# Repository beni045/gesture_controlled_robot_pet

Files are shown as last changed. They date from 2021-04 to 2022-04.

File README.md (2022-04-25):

# Gesture Controlled Robot Pet

Consider having a pet that is smart, responds to your commands without training, and even takes pictures for you! You don’t even have to pick up after or buy kibble for this pet! This is a dream come true for those craving an animal companion but cannot afford the time, money, or maintenance required for real animals. Robot pets are one example of how technology can assist in scenarios where companionship and fun are needed, but the handling and upkeep of real pets isn’t possible; especially in healthcare or senior homes.

Apart from doing normal pet things such as moving around and performing a few tricks, it can also perform robot tasks, like capturing photos with the camera in its nose. It can also remember you and follow you around for as long as you like. You can also deactivate this pet for some privacy and activate it back again when you feel like you need its company.

Through its camera “eyes”, this robot pet uses a combination of machine learning and computer vision techniques to see and respond to commands given through its owner’s body gestures. The robot pet can track, recognize, and perform a task such as following the user. The user is thus able to control the pet from a distance, enabling full autonomy.

<p align="center">
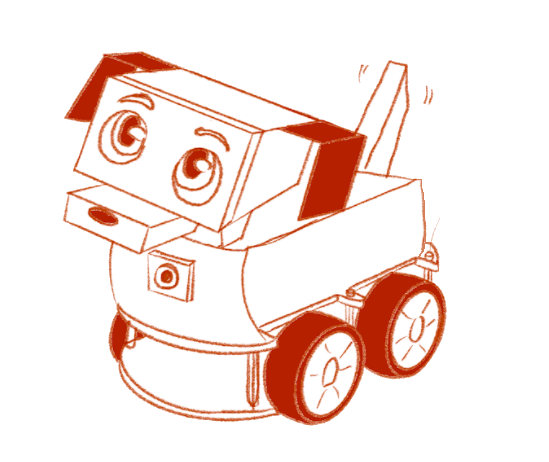
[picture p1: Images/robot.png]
  
</p>

# Repo
<p align="center">
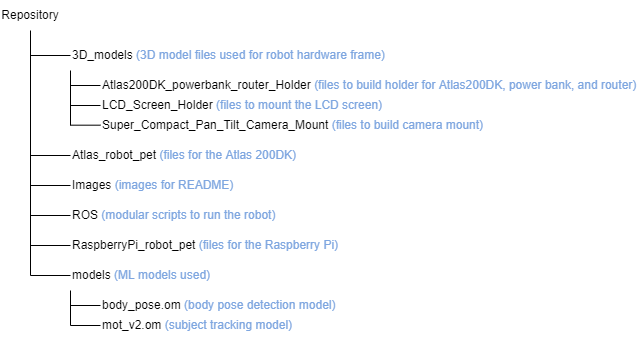
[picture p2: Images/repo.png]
  
</p>

# Gestures
Below are the gestures included in the repository.

Command | Gesture | Description | Output
------- | ------- | ----------- | ------
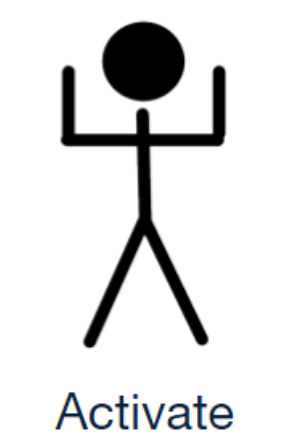
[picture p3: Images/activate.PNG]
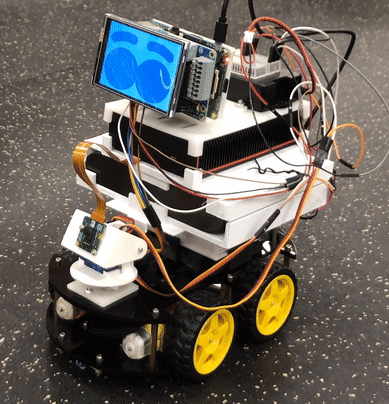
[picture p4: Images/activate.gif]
`Activate` |  | Robot starts functioning and responding to commands | 
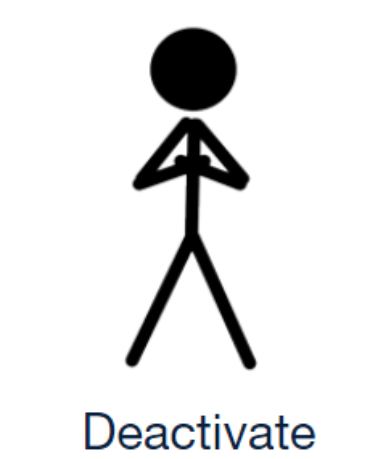
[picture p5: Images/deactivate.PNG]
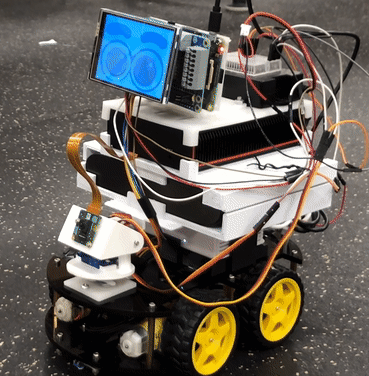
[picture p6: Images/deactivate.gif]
`Deactivate` |  | Robot goes to “sleep” state and can only be woken up by giving it activate command | 
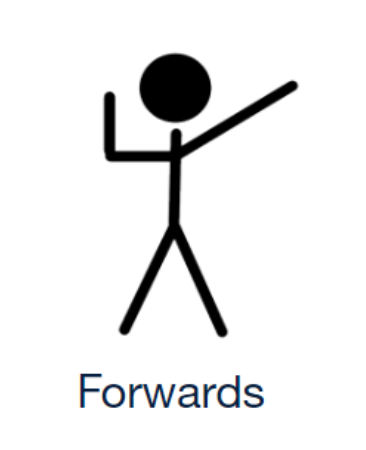
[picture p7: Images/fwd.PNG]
`Move Forwards` |  | Moves the robot forwards | 
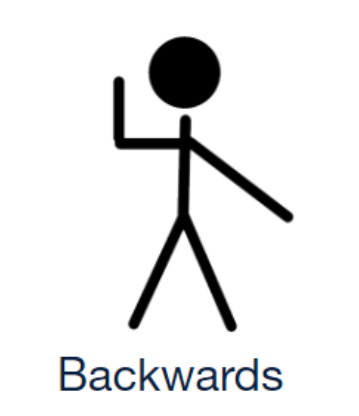
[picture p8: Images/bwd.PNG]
`Move Backwards` |  | Moves the robot backwards | 
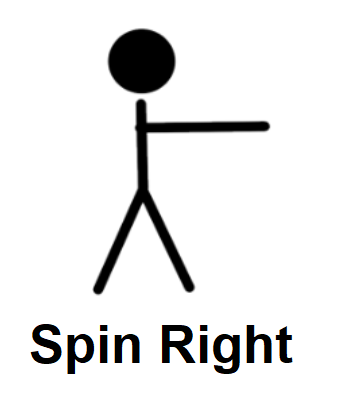
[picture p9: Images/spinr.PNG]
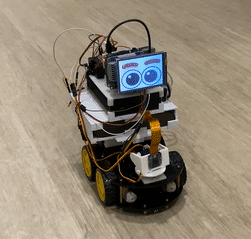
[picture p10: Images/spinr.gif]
`Spin Right` |  | Spins the robot right | 
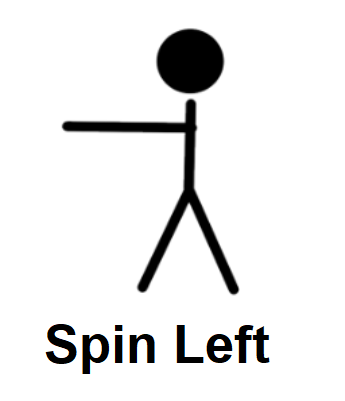
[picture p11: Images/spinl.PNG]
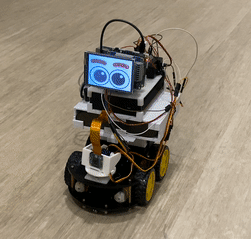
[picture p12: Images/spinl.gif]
`Spin Left` |  | Spins the robot left | 
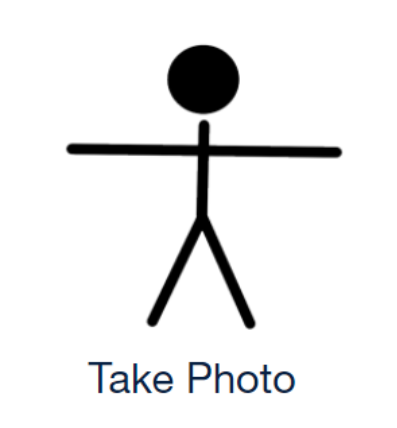
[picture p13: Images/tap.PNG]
`Take a Picture` |  | Initiates the routine to take a photo | 
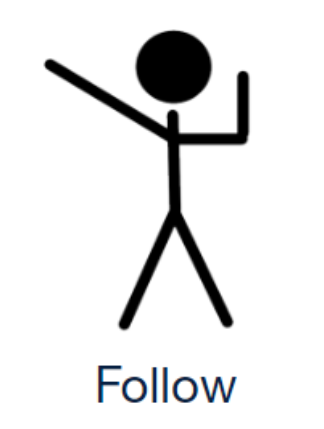
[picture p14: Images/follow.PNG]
`Follow` |  | Initiates the routine to follow the person who gave the follow gesture | 
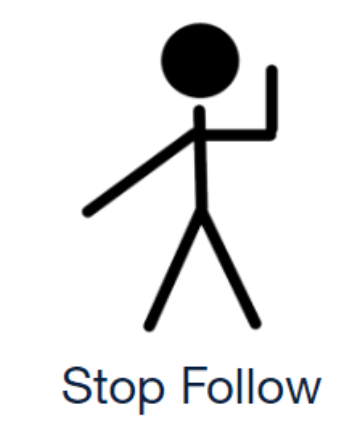
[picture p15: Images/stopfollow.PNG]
`Stop Follow` |  | Stops the follow routine if the robot is in follow mode | 

# Hardware
* [Huawei's Atlas 200DK](https://e.huawei.com/en/products/cloud-computing-dc/atlas/atlas-200)
* [Raspberry Pi (3+)](https://www.raspberrypi.org/products/raspberry-pi-4-model-b/)
* [Raspberry Pi Camera (Camera V2)](https://www.raspberrypi.org/products/camera-module-v2/)
* [Raspberry Pi LCD Screen (Kuman 3.5" Inch TFT LCD Display 480x320 RGB Pixels)](https://www.amazon.ca/Kuman-Display-480x320-Raspberry-Interface/dp/B01CQIPEO0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)
* [ELEGOO UNO Robot Car Base](https://www.amazon.ca/ELEGOO-Ultrasonic-Bluetooth-Intelligent-Educational/dp/B07485YQP8)
* [2 Servo Motors (SG90)](https://www.amazon.ca/gp/product/B07Z16DWGW/ref=ppx_yo_dt_b_asin_title_o05_s00?ie=UTF8&psc=1)
* [Krisdonia Power Bank](https://www.amazon.ca/Krisdonia-25000mAh-Portable-External-Macbooks/dp/B076GYGR6M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)
* [GL.iNet Router](https://www.gl-inet.com/products/gl-ar750/)

* Miscellaneous:
  * 3D printer
  * [Raspberry Pi Camera Ribbon Cable](https://www.amazon.ca/Raspberry-Camera-Ribbon-Cable-Module/dp/B0981DPWD9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)
  * 2 Ethernet Cables
  * Breadboard Jumper Cables
  * Screws

<p align="center">
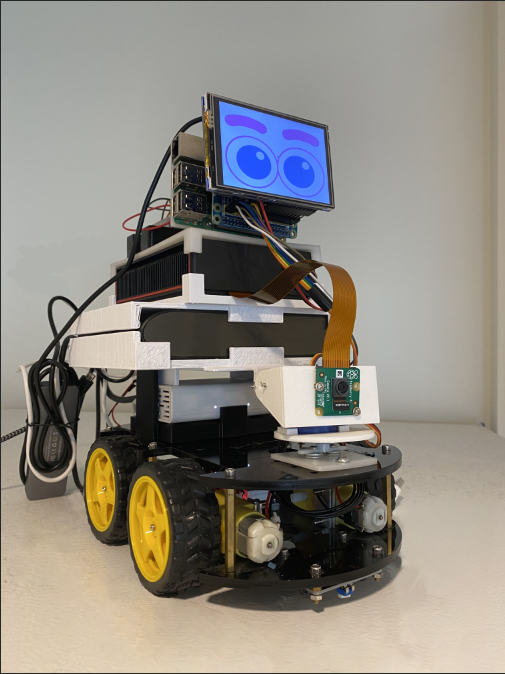
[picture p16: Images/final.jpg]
  
</p>

### Setup and Connection Notes
* Build robot base without using the Arduino or the ultrasonic sensors, you can find the instructions [here](https://drive.google.com/file/d/1nSlkYJ7oCfMkG1p-KDfVHdLQt3B4Nmo5/view)
* Connect robot base parts to Raspberry Pi (see pinout in RaspberryPi_robot_pet/server_v9.py)
* Connect Raspberry Pi Camera to CAMERA1 on the Atlas 200 DK, you can follow this [guide](https://support.huaweicloud.com/intl/en-us/qs-atlas200dkappc32/atlased_04_0006.html)
* Set the output voltage of the power bank to 12 V. (Hold the power button and then double click a few times.)
  * The Atlas Board can be connected to the "DC-Out" port; the router and the Pi can be connected to the USB ports.
* [Router connection](https://github.com/kylerhunag/gesture_controlled_robot_pet/wiki/Router-Connection-Setup-Guide) (After you've completed 1st step of [Atlas 200DK Setup](https://github.com/kylerhunag/gesture_controlled_robot_pet/edit/main/README.md#atlas-200dk-setup) and 2nd step of [Raspberry Pi Setup](https://github.com/kylerhunag/gesture_controlled_robot_pet/edit/main/README.md#raspberry-pi-setup))
  * Raspberry Pi connected to Atlas 200DK via wireless connection
  * Atlas 200DK connected to the router via Ethernet cord
  * Laptop connected to the router via wireless connection

# Setup
### Development Environment (PC)
Development PC requires Ubuntu 18.04 system (can be virtual machine), and have CANN installed. Please setup follow the this official [guide](https://support.huaweicloud.com/intl/en-us/environment-deployment-Atlas200DK202/atlased_04_0017.html) or this [wiki](https://gitee.com/ascend/samples/wikis/Setting%20Up%20the%20Development%20and%20Operating%20Environments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)

### Atlas 200DK Setup
1. Setup the Atlas 200 DK board, following this [wiki](https://gitee.com/ascend/samples/wikis/Setting%20Up%20the%20Development%20and%20Operating%20Environments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) or the official [guide](https://support.huaweicloud.com/intl/en-us/environment-deployment-Atlas200DK202/atlased_04_0001.html)

2. Power the Atlas DK board and set up the router connections. You can follow this [guide](https://github.com/kylerhunag/gesture_controlled_robot_pet/wiki/Router-Connection-Setup-Guide)

3. Attach raspberry Pi camera to the board (https://support.huaweicloud.com/intl/en-us/qs-atlas200dkappc32/atlased_04_0006.html).  

4. Set up RC Car by following instructions [here](https://drive.google.com/file/d/1nSlkYJ7oCfMkG1p-KDfVHdLQt3B4Nmo5/view).

5. On Atlas 200 DK, git clone this repo 
    (No internet access? Just try connecting Atlas 200 Dk to a router with Ethernet Cable. For details, check [official document](https://support.huaweicloud.com/intl/en-us/environment-deployment-Atlas200DK1012/atlased_04_0012.html) or [our router connection guide](https://github.com/kylerhunag/gesture_controlled_robot_pet/wiki/Router-Connection-Setup-Guide)) 

    `git clone https://github.com/kylerhunag/gesture_controlled_robot_pet.git`
   
6. Install the required dependencies to run this project:

    `cd ~/gesture_controlled_robot_pet/Atlas_robot_pet`
    
    `pip3 install -r requirements.txt`
  
### Robot Operating System (ROS) Setup

The Robot Operating System (ROS) is a set of software libraries and tools that help you build robot applications. In order to set up ROS on the Atlas 200 DK board refer to the following guide below: 

[ROS Setup](https://hiascend.notion.site/UBC-Capstone-ROS-on-Atlas200DK-0720a3605a354f36a9cdbb0ce885ddf2)

Once the conda environment and ROS has been set up on the board we have to create a workspace and a ROS project such that we can run our code. The following code describes how to do so:
* [ROS Create Workspace](http://wiki.ros.org/catkin/Tutorials/create_a_workspace)
* [ROS Create Package](http://wiki.ros.org/ROS/Tutorials/CreatingPackage)
* [ROS Build Package](http://wiki.ros.org/ROS/Tutorials/BuildingPackages)

1. Once you have created and built your ROS package you can now copy paste the `scripts` and `launch` folder from `~/gesture_controlled_robot_pet/ROS` to `~/catkin_ws/src/<package_name>/`

2. Here we used robot_pet as our package_name.
   Once all the scripts and launch files are copied into the catkin_ws we need to make the files executable and as such do `chmod +x <file name>` for all the files that have been copied. Before running the ROS project ensure that the presenter server script is running and the Raspberry PI script is running. 

3. Activate the environment you just created. Install the dependencies listed in the `requirements.txt`. And lastly run:
  
`cd ~/catkin_ws` 
  
`source ./devel/setup.bash`
 
`catkin_make` to build the nodes.

### Raspberry Pi Setup
1. Install the latest version of Raspbian onto an SD card  
   Follow the steps in the link:  
   https://www.raspberrypi.org/documentation/installation/installing-images/ 
2. Insert SD card into Pi and power on the Pi by plugging it into a 5V power source.
3. Make sure you complete the [Router connection](https://github.com/kylerhunag/gesture_controlled_robot_pet/wiki/Router-Connection-Setup-Guide)
4. Update the system by opening a terminal and entering:  
   `sudo apt-get update`                                                        
   `sudo apt-get upgrade`                                                        
   `sudo apt-get install python3-pip`                                                        
   `sudo apt install unclutter`
5. Retrieve the files to be downloaded onto the Raspberry Pi, which are located in the folder “RaspberryPi_robot_pet”, either from cloning this repository or from the GitHub repository directly. Make sure the following files are in a folder called “RaspberryPi_robot_pet”:
    * Raspberry-Pi_robot_pet/happy.mp4
    * Raspberry-Pi_robot_pet/neu.mp4
    * Raspberry-Pi_robot_pet/white.jpeg
    * Raspberry-Pi_robot_pet/body_img.jpg
    * Raspberry-Pi_robot_pet/camera_img.jpg
    * Raspberry-Pi_robot_pet/deactivate.jpg
    * Raspberry-Pi_robot_pet/follow_img.jpg
    * Raspberry-Pi_robot_pet/server_v9.py
    * Raspberry-Pi_robot_pet/requirements.txt
6. Navigate to the directory where the main Raspberry Pi program is located, for example:  
   `cd /home/pi/Documents/Capstone/Raspberry-Pi_robot_pet/`
7. Install OpenCV and numpy for Python 3:  
   `pip3 install -r requirements.txt`
8. Install the LCD driver  
   Follow instruction under the link:  
   https://github.com/goodtft/LCD-show 

# Run the Robot

### Raspberry Pi
1. Start Raspberry Pi into Raspbian OS
2. ssh into the Pi 
3. Navigate to the directory where the main Raspberry Pi program is located, for example:  
   `cd /home/pi/Documents/Capstone/Raspberry-Pi_robot_pet/`
4. Ensure that Pi and the Atlas 200DK are in the same network. Run the main program for the robot control:  
   `python3 server_v9.py`

### Atlas 200DK 
1. Login to Atlas 200 DK from PC (Refer to this [guide](https://hiascend.notion.site/Atlas-200-DK-Setup-Guide-070b907c3c124381bdd6721618b81ef8) on how to setup and access). Note, it is required to use `VScode` with `Remote-SSH` extension to login remotely, otherwise you might not get the video stream to display on your PC.

2. Navigate to the presenter server directory and start the presenter server: 

    `cd ~/gesture_controlled_robot_pet/Atlas_robot_pet/presenterserver`
    
    `bash run_presenter_server.sh body_pose.conf`

### Robot Operating System (ROS) on 200DK

The ROS project can now be run. In order to run the project refer to the following set of commands: 
  
`cd ~/catkin_ws` 
  
`source ./devel/setup.bash`
  
`roslaunch <package_name> robot_pet_launch.launch`

# Third Party Links
* Body Pose Model: Sample Body Pose https://github.com/Atlas200dk/sample_bodypose
* Object Detection Model: FairMOT model https://github.com/HardysJin/atlas-track
* Raspbian image: https://www.raspberrypi.org/documentation/installation/installing-images/ 
* Presenter server & ROS: https://github.com/Ascend-Huawei/HiFly_Drone
* LCD driver: https://github.com/goodtft/LCD-show

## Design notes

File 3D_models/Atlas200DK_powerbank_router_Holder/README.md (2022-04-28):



1. DK_holder_main: The top holder of Atlas 200DK 

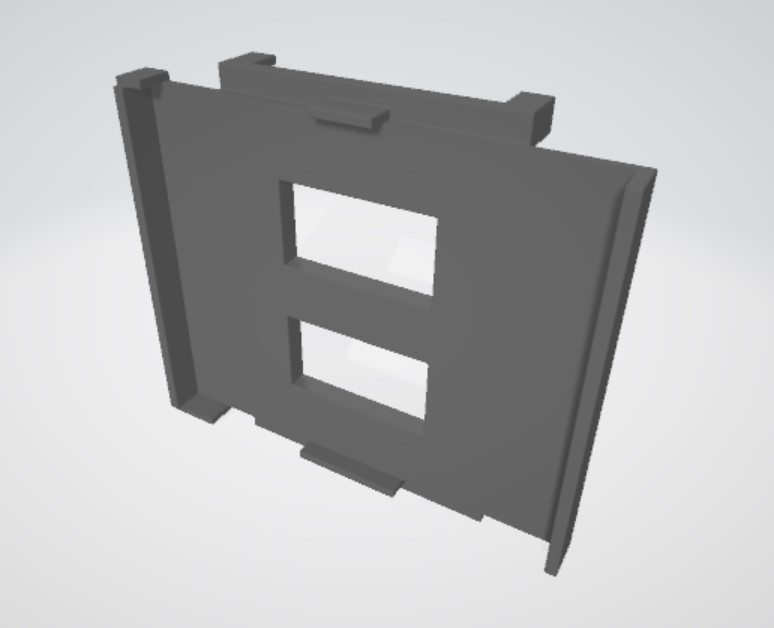
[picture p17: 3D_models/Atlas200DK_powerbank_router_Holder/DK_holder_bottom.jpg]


2. DK_holder_bottom: The bottom holder of Atlas 200DK, connected to the top of the power bank

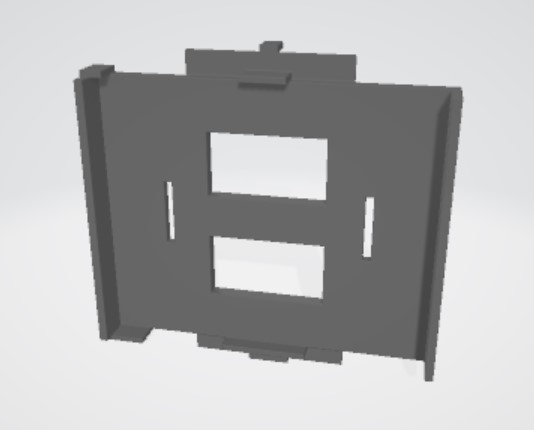
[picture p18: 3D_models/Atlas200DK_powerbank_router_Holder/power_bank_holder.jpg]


3. power_bank_holder: The bottom holder of the power bank, connected to the router holder

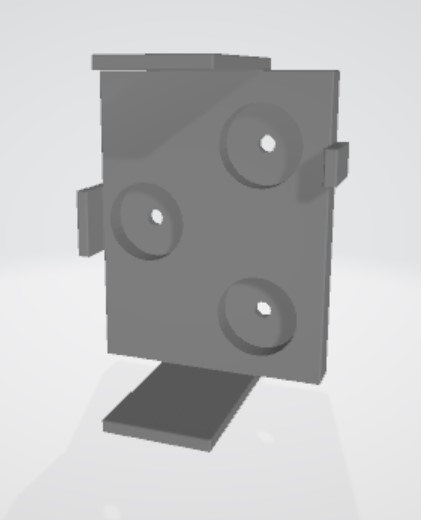
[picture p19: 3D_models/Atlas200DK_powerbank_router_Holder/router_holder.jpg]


4. router_holder: The holder of router, can be inserted into the bottom holder of the power bank

Instructions on assembly: The bottom level is the router_holder which can be either screwed in or glued on to the RC car base. The middle level is the power_bank_holder which has two rectangular holes that can be inserted on top of the router_holder. The top level is the DK_holder_bottom which also acts as the cover of the power bank. It should be put on after you place the power bank and the DK board goes on top. 

Remember to leave all ports facing to the back of the robot so that all cables can fit.

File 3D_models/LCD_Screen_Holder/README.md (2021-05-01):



1. Screen_Holder: Connect the raspberry Pi to this part with Screws and Bolts



2. DK_Cup_Screen: the part connect with DK holder and screen holder

Finsihed View: 



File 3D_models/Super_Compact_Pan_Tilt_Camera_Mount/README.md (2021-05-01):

# Camera Mount
A simple camera servo mount to enable the pet to keep the user in the center.  
This mount uses SG90 servo motors to move the camera up, down, left and right.

<p align="center">
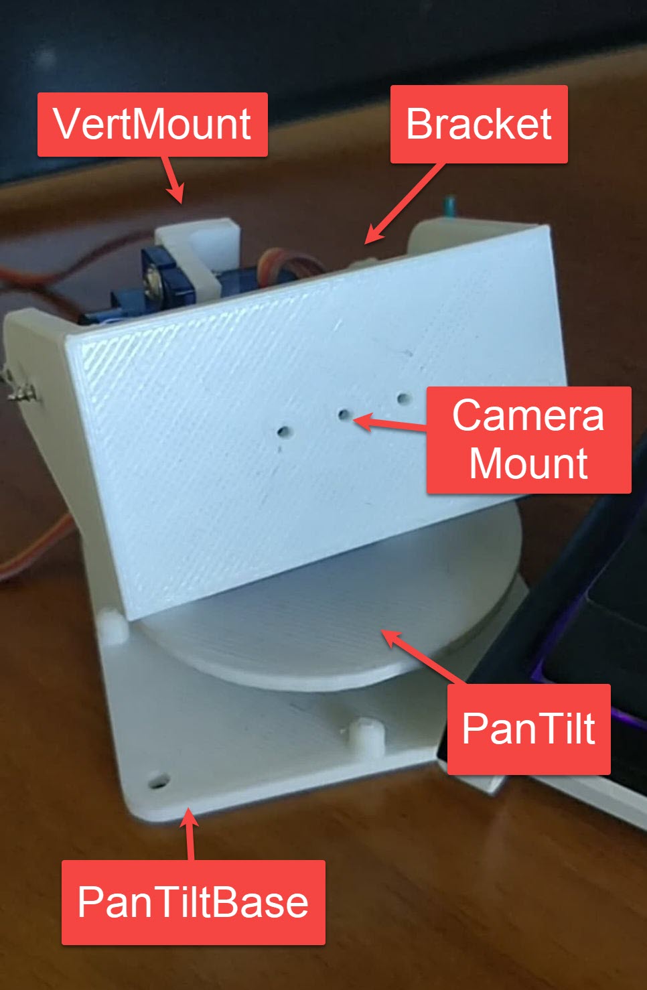
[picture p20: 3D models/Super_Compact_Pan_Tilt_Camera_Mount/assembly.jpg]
  
</p>

Print all parts and fix servos with the appropiate screws.  
The VerMount and PanTilt parts have screws and the appropriate slots for the servo motors.

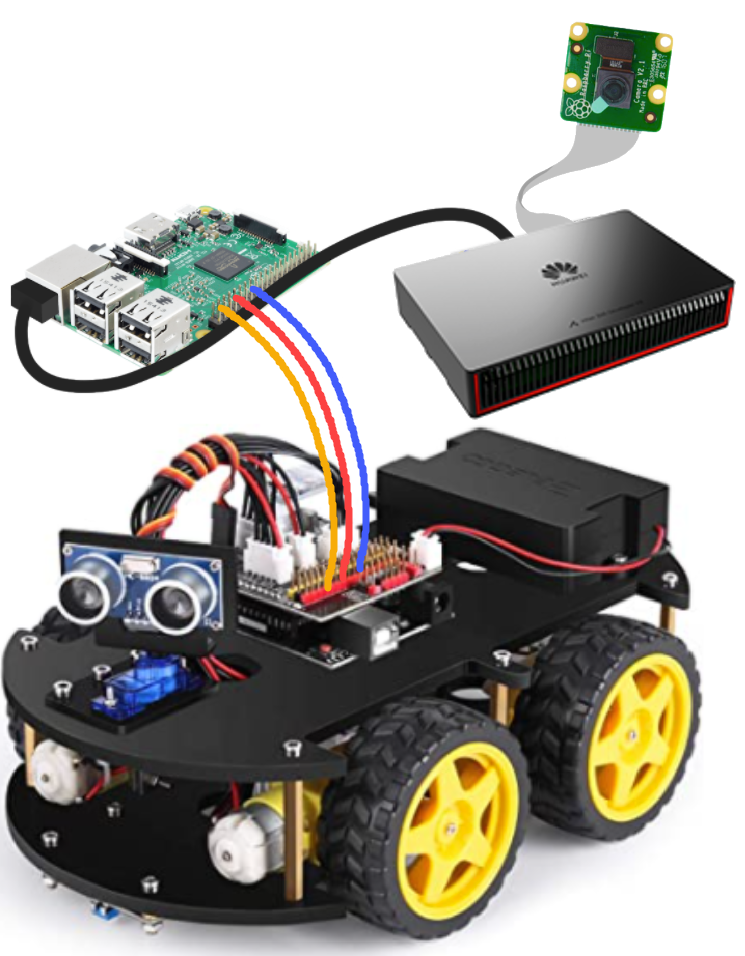
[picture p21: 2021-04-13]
Images/robot_chain.png

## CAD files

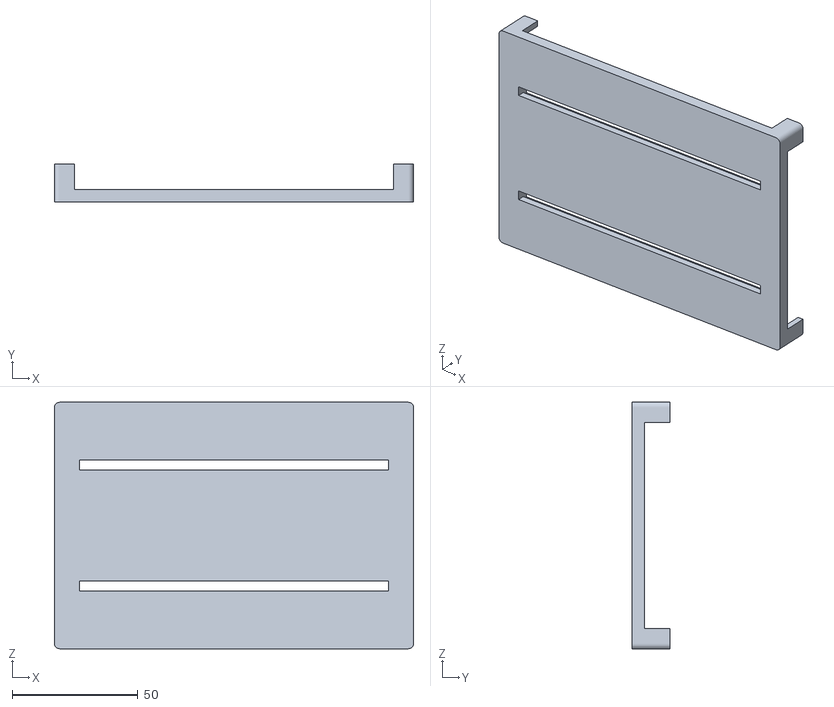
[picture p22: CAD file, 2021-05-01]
3D_models/Atlas200DK_powerbank_router_Holder/DK_holder_main.STL
143.0 x 15.0 x 98.2

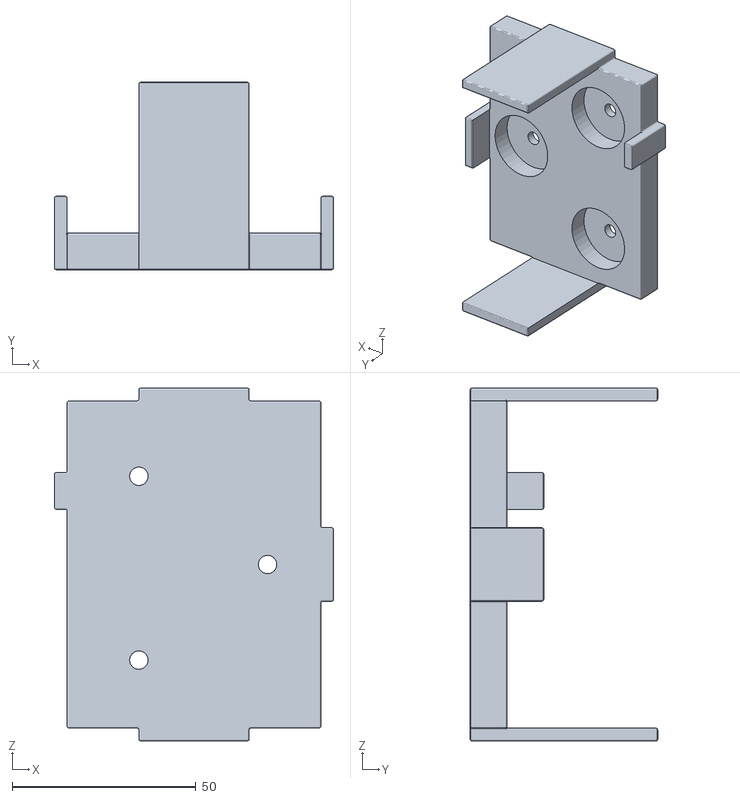
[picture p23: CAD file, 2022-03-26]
3D_models/Atlas200DK_powerbank_router_Holder/router holder.STL
76.0 x 51.0 x 96.0

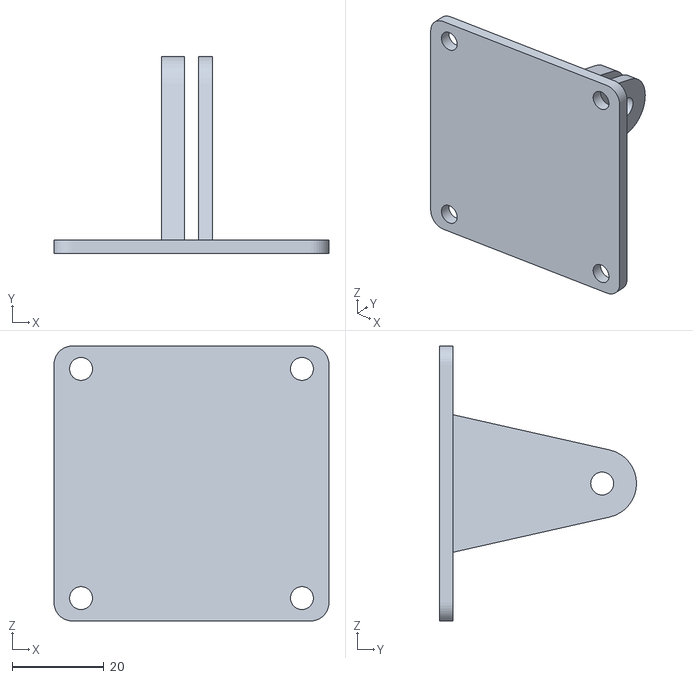
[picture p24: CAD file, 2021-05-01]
3D_models/LCD_Screen_Holder/DK_Cup_screen.STL
60.0 x 43.0 x 60.0

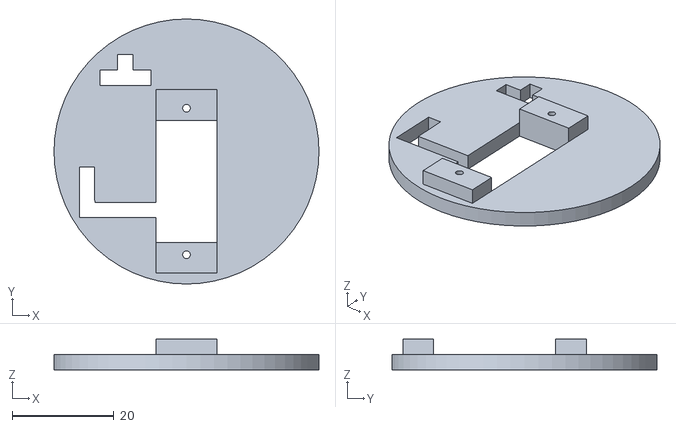
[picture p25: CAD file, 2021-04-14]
3D_models/Super_Compact_Pan_Tilt_Camera_Mount/panTilt.STL
52.0 x 52.0 x 6.00

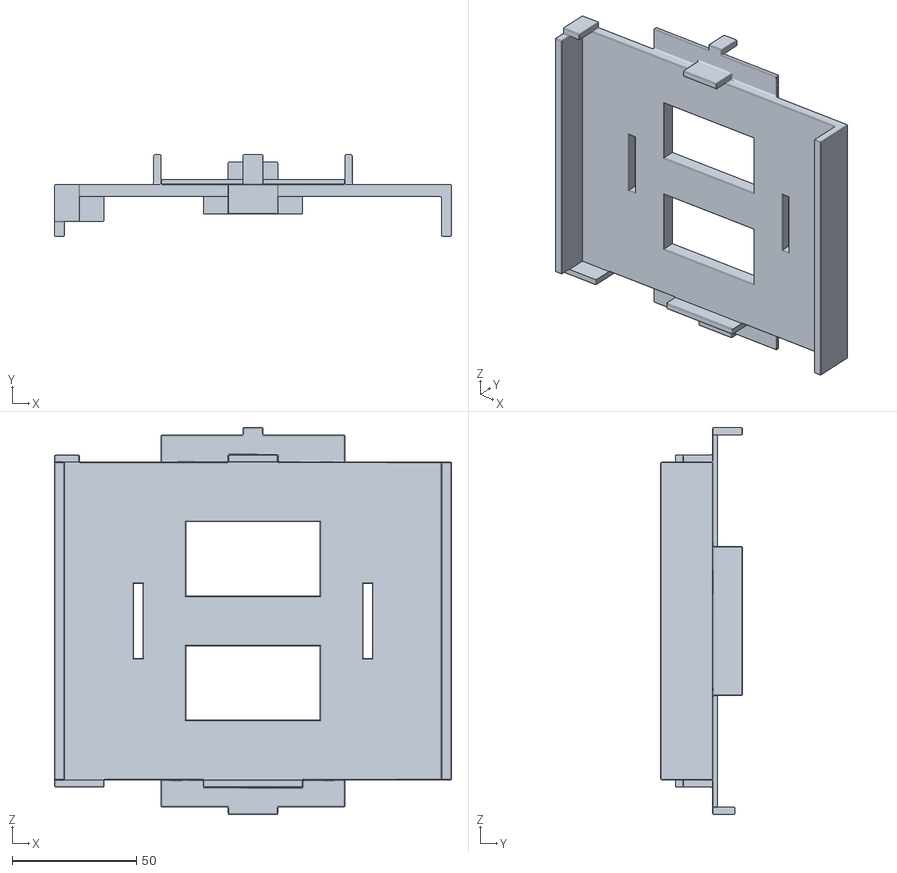
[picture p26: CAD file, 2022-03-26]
3D_models/Atlas200DK_powerbank_router_Holder/power_bank_holder.STL
160.0 x 33.0 x 156.0

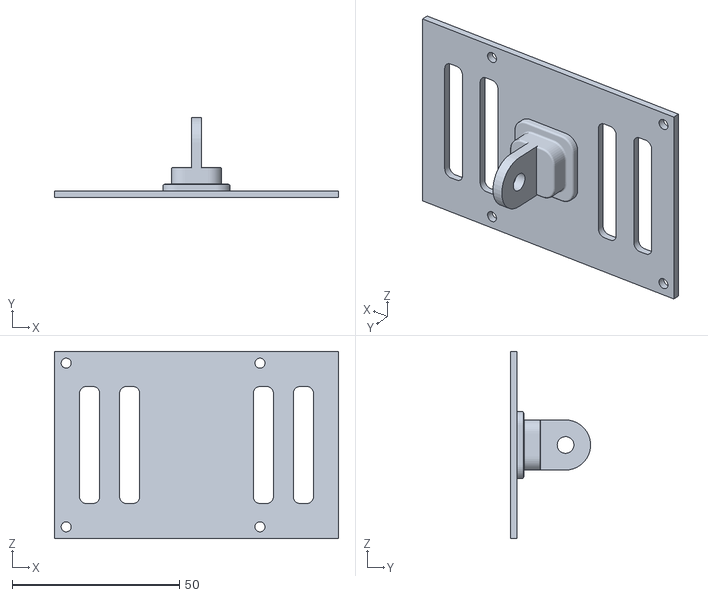
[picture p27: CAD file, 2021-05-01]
3D_models/LCD_Screen_Holder/Screen_holder.STL
85.0 x 24.0 x 56.0

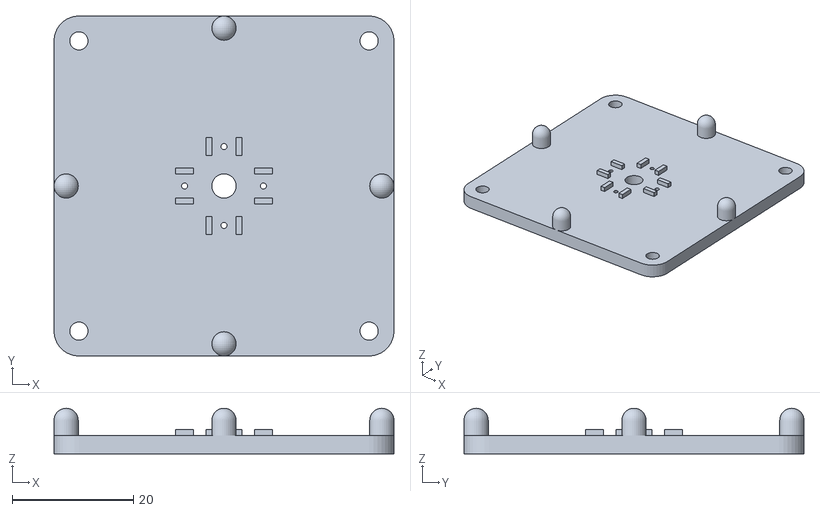
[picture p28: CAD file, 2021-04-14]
3D_models/Super_Compact_Pan_Tilt_Camera_Mount/panTiltBase.STL
56.0 x 56.0 x 7.50

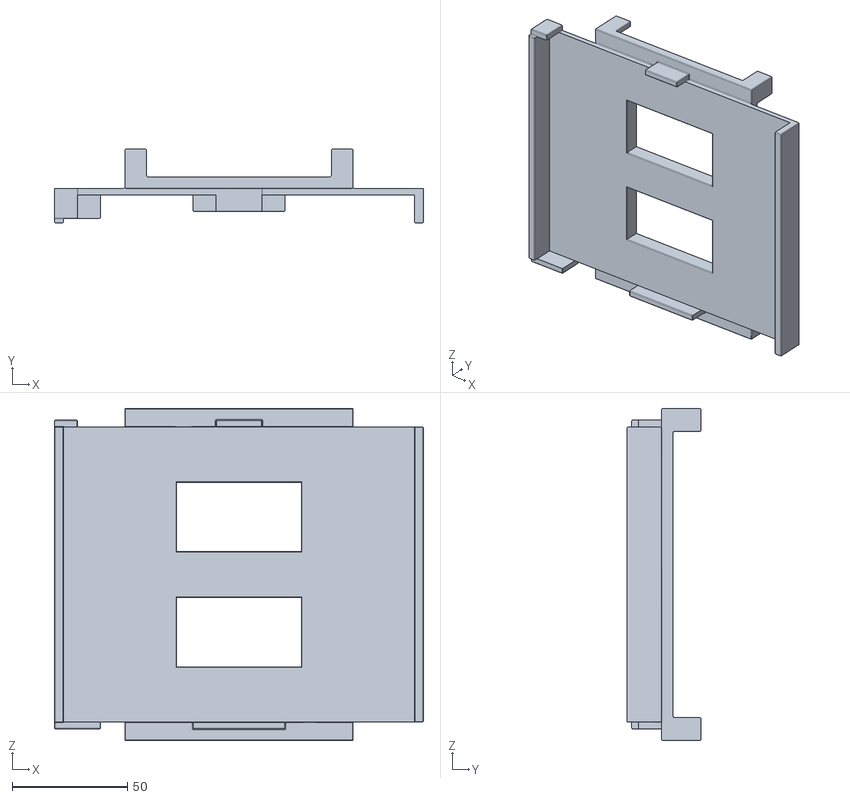
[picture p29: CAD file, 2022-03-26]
3D_models/Atlas200DK_powerbank_router_Holder/DK_holder_bottom.STL
160.0 x 32.0 x 144.0

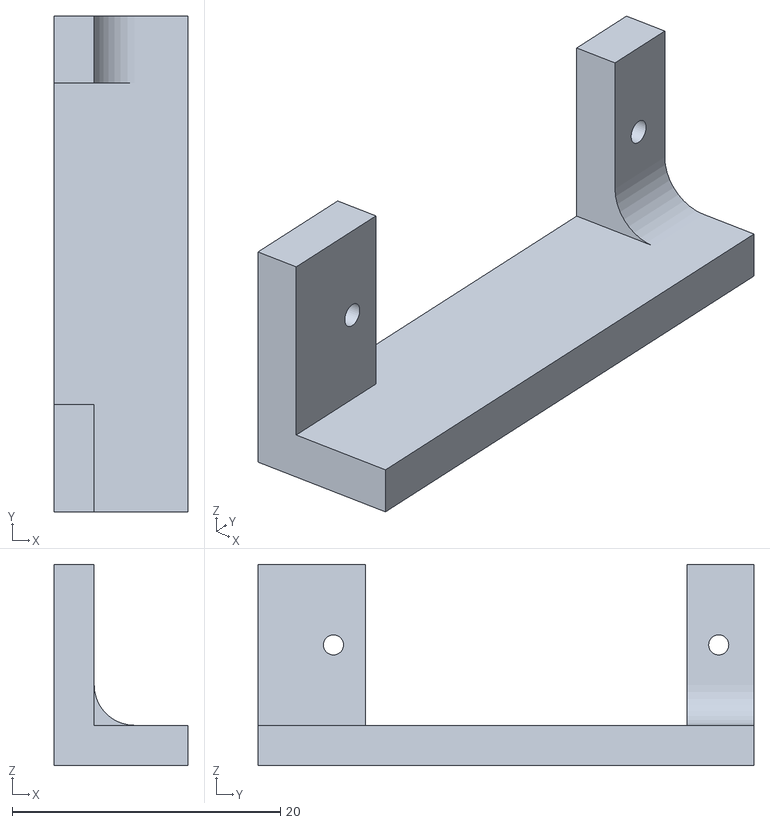
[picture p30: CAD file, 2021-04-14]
3D_models/Super_Compact_Pan_Tilt_Camera_Mount/vertMount.STL
10.00 x 37.0 x 15.0

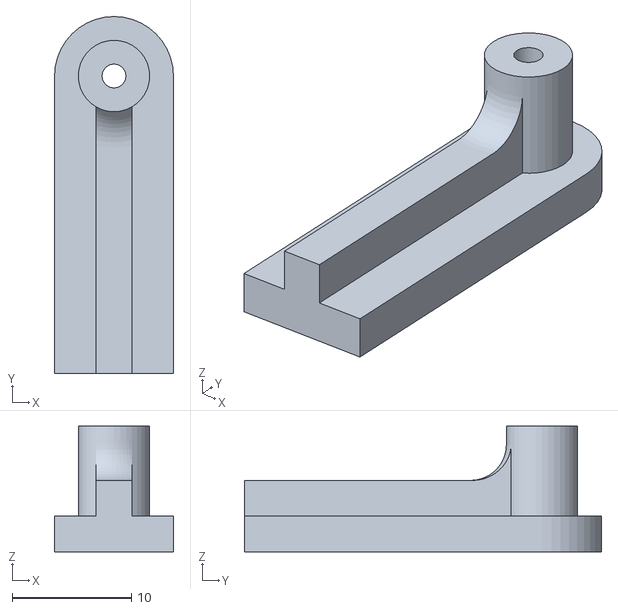
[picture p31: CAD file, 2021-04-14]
3D_models/Super_Compact_Pan_Tilt_Camera_Mount/bracket.STL
10.0 x 30.0 x 10.6

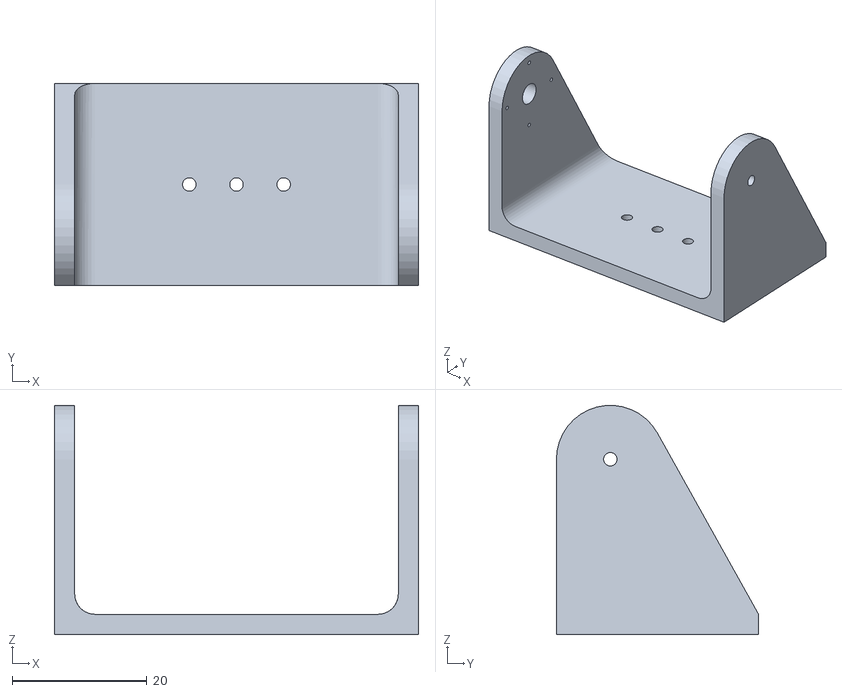
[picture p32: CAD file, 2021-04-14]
3D_models/Super_Compact_Pan_Tilt_Camera_Mount/cameraMount.STL
54.0 x 30.0 x 34.0

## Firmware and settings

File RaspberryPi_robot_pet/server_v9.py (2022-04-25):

import socket
import cv2
import pickle
import numpy as np
import struct
import RPi.GPIO as GPIO
import time
import socket
import os
import math
import threading
import datetime

# Pins for Servos
SERVO_X = 20
SERVO_Z = 21
START_X = 80
START_Z = 20

# Set GPIO numbering mode
GPIO.setmode(GPIO.BCM)
GPIO.setwarnings(False)

# Global for angle value
x_position = START_X
z_position = START_Z

# Set pins 11 & 12 as outputs, and define as PWM servo1 & servo2
GPIO.setup(SERVO_X,GPIO.OUT)
servo_x = GPIO.PWM(SERVO_X,50) # pin 11 for servo_x, pulse 50Hz
GPIO.setup(SERVO_Z,GPIO.OUT)
servo_z = GPIO.PWM(SERVO_Z,50) # pin 12 for servo_z, pulse 50Hz

#RC car base pins
in1 = 5
in2 = 6
en = 13
in3 = 19
in4 = 26 
en2 = 12
temp1=1

# Setting up for Camera View/GUI
width=480
height=320

font = cv2.FONT_HERSHEY_SIMPLEX
scale = 5
color = (0, 0, 255)
thickness = 10

white_img = np.zeros([512,512,3],dtype=np.uint8)
white_img.fill(255)
white_img = cv2.resize(white_img, (width, height))

display = "deactivate"
deactivate_img = cv2.imread("/home/pi/Documents/Capstone/Raspberry-Pi_robot_pet/deactivate.jpg")
follow_img = cv2.imread("/home/pi/Documents/Capstone/Raspberry-Pi_robot_pet/follow_img.jpg")
camera_img = cv2.imread("/home/pi/Documents/Capstone/Raspberry-Pi_robot_pet/camera_img.jpg")
body_img = cv2.imread("/home/pi/Documents/Capstone/Raspberry-Pi_robot_pet/body_img.jpg")

os.system("unclutter -idle 0 &") #Hide mouse pointer

#Set up serial communication w/ Atlas 200DK

UDP_IP = "0.0.0.0" # listen to everything
UDP_PORT = 12345 # port

s = socket.socket(socket.AF_INET,socket.SOCK_STREAM)
s.bind((UDP_IP, UDP_PORT))

s.listen(10)
print('Socket now listening')

conn,addr=s.accept()
print(addr)

###########################
### Servo Motor Control ###
###########################

def go_to_angle(servo, angle):
    servo.ChangeDutyCycle(2+(angle/18))
    time.sleep(0.5)
    servo.ChangeDutyCycle(0)
    
def move_up():
    global z_position

    if z_position - 700 > 0:
        z_position = 0
    else:
        z_position = z_position + 5

    go_to_angle(servo_z, z_position)
    
def move_down():
    global z_position
    # Bound z_position
    if z_position - 5 < 0:
        z_position = 0
    else:
        z_position = z_position - 5
    go_to_angle(servo_z, z_position)

def move_left():
    global x_position

    if x_position - 700 > 0:
        x_position = 0
    else:
        x_position = x_position + 5

    go_to_angle(servo_x, x_position)

def move_right():
    global x_position

    if x_position -5 < 0:
        x_position = 0
    else:
        x_position = x_position - 5
        
    go_to_angle(servo_x, x_position)

#############################
### RC Car Control Thread ###
#############################

def RC_car_control():
  global current_hg_command

  while True:
    time.sleep(0.0000000001)

    if current_hg_command == "forwards":
      GPIO.output(in1,GPIO.HIGH)
      GPIO.output(in2,GPIO.LOW)
      GPIO.output(in3,GPIO.LOW)
      GPIO.output(in4,GPIO.HIGH)
      time.sleep(0.5)
      GPIO.output(in1,GPIO.LOW)
      GPIO.output(in2,GPIO.LOW)
      GPIO.output(in3,GPIO.LOW)
      GPIO.output(in4,GPIO.LOW)
      current_hg_command = "send_done_command"

    if current_hg_command == "backwards":
      GPIO.output(in1,GPIO.LOW)
      GPIO.output(in2,GPIO.HIGH)
      GPIO.output(in3,GPIO.HIGH)
      GPIO.output(in4,GPIO.LOW)
      time.sleep(0.5)
      GPIO.output(in1,GPIO.LOW)
      GPIO.output(in2,GPIO.LOW)
      GPIO.output(in3,GPIO.LOW)
      GPIO.output(in4,GPIO.LOW)
      current_hg_command = "send_done_command"

    elif current_hg_command == "spin_left":
      GPIO.output(in1,GPIO.HIGH)
      GPIO.output(in2,GPIO.LOW)
      GPIO.output(in3,GPIO.LOW)
      GPIO.output(in4,GPIO.LOW)
      time.sleep(1)
      GPIO.output(in1,GPIO.LOW)
      GPIO.output(in2,GPIO.LOW)
      GPIO.output(in3,GPIO.LOW)
      GPIO.output(in4,GPIO.LOW)

      current_hg_command = "send_done_command"

    elif current_hg_command == "spin_right":
      GPIO.output(in1,GPIO.LOW)
      GPIO.output(in2,GPIO.LOW)
      GPIO.output(in3,GPIO.LOW)
      GPIO.output(in4,GPIO.HIGH)
      time.sleep(1)
      GPIO.output(in1,GPIO.LOW)
      GPIO.output(in2,GPIO.LOW)
      GPIO.output(in3,GPIO.LOW)
      GPIO.output(in4,GPIO.LOW)
      current_hg_command = "send_done_command"

    elif current_hg_command == "left":
      GPIO.output(in1,GPIO.HIGH)
      GPIO.output(in2,GPIO.LOW)
      GPIO.output(in3,GPIO.LOW)
      GPIO.output(in4,GPIO.LOW)
      time.sleep(0.5)
      GPIO.output(in1,GPIO.LOW)
      GPIO.output(in2,GPIO.LOW)
      GPIO.output(in3,GPIO.LOW)
      GPIO.output(in4,GPIO.LOW)
      current_hg_command = "send_done_command"
    
    elif current_hg_command == "right":
      GPIO.output(in1,GPIO.LOW)
      GPIO.output(in2,GPIO.LOW)
      GPIO.output(in3,GPIO.LOW)
      GPIO.output(in4,GPIO.HIGH)
      time.sleep(0.5)
      GPIO.output(in1,GPIO.LOW)
      GPIO.output(in2,GPIO.LOW)
      GPIO.output(in3,GPIO.LOW)
      GPIO.output(in4,GPIO.LOW)
      current_hg_command = "send_done_command"
        
###########################

#Initialize serial communication w/ Atlas 200DK
data = b""
payload_size = struct.calcsize(">L")
print("payload_size: {}".format(payload_size))

#Initialize Servo
servo_x.start(0)
servo_z.start(0)

print ("Servo Control Started")

go_to_angle(servo_x, START_X)
go_to_angle(servo_z, START_Z)

#Initialize command SM and mood expression/GUI
global current_hg_command
current_hg_command = "none"

count_forward = 0
count_backward = 0
count_spin = 0
count_takeapicture = 0

count_num = 1 #number of commands in a row sent from Atlas before command is executed

neu_cap = cv2.VideoCapture("./neu.mp4")
# happy_cap = cv2.VideoCapture("./happy.mp4")

cv2.namedWindow('ImageWindow', cv2.WINDOW_NORMAL)
cv2.setWindowProperty('ImageWindow', cv2.WND_PROP_FULLSCREEN, cv2.WINDOW_FULLSCREEN)

#####################################
### Initialization of RC car base ###
#####################################

GPIO.setmode(GPIO.BCM)
GPIO.setup(in1,GPIO.OUT)
GPIO.setup(in2,GPIO.OUT)
GPIO.setup(en,GPIO.OUT)
GPIO.setup(in3,GPIO.OUT)
GPIO.setup(in4,GPIO.OUT)
GPIO.setup(en2,GPIO.OUT)
GPIO.output(in1,GPIO.LOW)
GPIO.output(in2,GPIO.LOW)
GPIO.output(in3,GPIO.LOW)
GPIO.output(in4,GPIO.LOW)
p=GPIO.PWM(en,1000)
p.start(100)
p2=GPIO.PWM(en2,1000)
p2.start(100)
print("\n")
print("The default speed & direction of motor is LOW & Forward.....")
print("r-run s-stop f-forward b-backward l-low m-medium h-high e-exit")
print("\n")

#RC Car base thread
t1 = threading.Thread(target = RC_car_control,args=())
t1.start()

###########################

while True:
    time.sleep(0.000000000001)
    data = b""

    # Receive data from Atlas 200DK
    while len(data) < payload_size:
        print("Recv: {}".format(len(data)))
        data += conn.recv(4096)

    print("Done Recv: {}".format(len(data)))
    packed_msg_size = data[:payload_size]
    data = data[payload_size:]
    msg_size = struct.unpack(">L", packed_msg_size)[0]
    print("msg_size: {}".format(msg_size))
    while len(data) < msg_size:
        data += conn.recv(4096)

    print("hg state:" + str(current_hg_command))

    frame_data = data[:msg_size]
    data = data[msg_size:]
    data=pickle.loads(frame_data, fix_imports=True, encoding="bytes")

    ###############################################
    ### Do something with data from Atlas 200DK ###
    ###############################################

    # Tell Atlas that any movement command is complete
    if current_hg_command == "send_done_command":
         data = pickle.dumps("done command\n", 0)
         size = len(data)
         conn.sendall(struct.pack(">L", size) + data) # Send data back to Atlas 200 DK
         current_hg_command = "none"

    # Execute and acknowledge reception of "Servo up" from Atlas
    elif data=="servo up\n":
            if current_hg_command == "none" or current_hg_command == "take_a_picture":
                move_up()
                print("Look up " + str(z_position))
            data = pickle.dumps("got it\n", 0)
            size = len(data)
            conn.sendall(struct.pack(">L", size) + data) # Send data back to Atlas 200 DK

    # Execute and acknowledge reception of "Servo down" from Atlas
    elif data=="servo down\n":
            if current_hg_command == "none" or current_hg_command == "take_a_picture":
                move_down()
                print("Look down " + str(z_position))
            data = pickle.dumps("got it\n", 0)
            size = len(data)
            conn.sendall(struct.pack(">L", size) + data) # Send data back to Atlas 200 DK

    # Execute and acknowledge reception of "Servo left" from Atlas
    elif data=="servo left\n":
            if current_hg_command == "none" or current_hg_command == "take_a_picture":
                move_left()
                print("Look left " + str(x_position))
            data = pickle.dumps("got it\n", 0)
            size = len(data)
            conn.sendall(struct.pack(">L", size) + data) # Send data back to Atlas 200 DK

    # Execute and acknowledge reception of "Servo right" from Atlas
    elif data=="servo right\n":
            if current_hg_command == "none" or current_hg_command == "take_a_picture":
                move_right()
                print("Look right " + str(x_position))
            data = pickle.dumps("got it\n", 0)
            size = len(data)
            conn.sendall(struct.pack(">L", size) + data) # Send data back to Atlas 200 DK

    #######################################################################################
    ### Sending information back to Atlas about which hand gesture command is executing ###
    #######################################################################################

    # Take a picture
    elif data=="take a picture\n":
            print("Take a picture")
            # display = "picture"
            if current_hg_command == "none":
                count_takeapicture = count_takeapicture + 1
                print("Takeapicture count:" + str(count_takeapicture))
                count_forward = 0
                count_backward = 0
                count_spin = 0
                if count_takeapicture == count_num:
                    print("Take a Picture triggered \n\n")
                    time_tap_start = 0
                    count_takeapicture = 0
                    current_hg_command = "take_a_picture"
                    data = pickle.dumps("received take a picture\n", 0)
                else:
                    data = pickle.dumps("got it \n", 0)
            else: 
                data = pickle.dumps("got it \n", 0)
            size = len(data)
            conn.sendall(struct.pack(">L", size) + data) # Send data back to Atlas 200 DK 

   # Move Forwards
    elif data=="forward\n":
            print("Forward")
            if current_hg_command == "none":
                count_forward = count_forward + 1
                print("Forwards count: " + str(count_forward))
                count_takeapicture = 0
                count_backward = 0
                count_spin = 0
                if count_forward == count_num:
                   print("Forwards triggered \n\n")
                   count_forward = 0
                   current_hg_command = "forwards"
                   data = pickle.dumps("received forward\n", 0)
                else: 
                   data = pickle.dumps("got it \n", 0)
            else: 
                data = pickle.dumps("got it \n", 0)
            size = len(data)
            conn.sendall(struct.pack(">L", size) + data) # Send data back to Atlas 200 DK 

    # Move Backwards
    elif data=="backward\n":
            print("Backward")
            if current_hg_command == "none":
                count_backward = count_backward + 1
                print("Backwards count: " + str(count_backward))
                count_takeapicture = 0
                count_forward = 0
                count_spin = 0
                if count_backward == count_num:
                    print("Backwards triggered \n\n")
                    count_backward = 0
                    current_hg_command = "backwards"
                    data = pickle.dumps("received backward\n", 0)
                else:
                    data = pickle.dumps("got it \n", 0)
            else: 
                data = pickle.dumps("got it \n", 0)
            size = len(data)
            conn.sendall(struct.pack(">L", size) + data) # Send data back to Atlas 200 DK 

    # Spin Left
    elif data=="spin left\n":
            print("Spin left")
            if current_hg_command == "none":
                count_spin = count_spin + 1
                print("Spin count: " + str(count_spin))
                count_takeapicture = 0
                count_forward = 0
                count_backward = 0
                if count_spin == count_num:
                    print("Spin triggered \n\n")
                    count_spin = 0
                    current_hg_command = "spin_left"
                    data = pickle.dumps("received spin left\n", 0)
                else:
                    data = pickle.dumps("got it \n", 0)
            else: 
                data = pickle.dumps("got it \n", 0)
            size = len(data)
            conn.sendall(struct.pack(">L", size) + data) # Send data back to Atlas 200 DK 

    # Spin Right
    elif data=="spin right\n":
            print("Spin right")
            if current_hg_command == "none":
                count_spin = count_spin + 1
                print("Spin count: " + str(count_spin))
                count_takeapicture = 0
                count_forward = 0
                count_backward = 0
                if count_spin == count_num:
                    print("Spin triggered \n\n")
                    count_spin = 0
                    current_hg_command = "spin_right"
                    data = pickle.dumps("received spin right\n", 0)
                else:
                    data = pickle.dumps("got it \n", 0)
            else: 
                data = pickle.dumps("got it \n", 0)
            size = len(data)
            conn.sendall(struct.pack(">L", size) + data) # Send data back to Atlas 200 DK

    # Left
    elif data=="left\n":
        print("Left")
        if current_hg_command == "none":
            count_takeapicture = 0
            count_forward = 0
            count_backward = 0
            print("Left triggered \n\n")
            current_hg_command = "left"
            data = pickle.dumps("received left\n", 0)
        else:
            data = pickle.dumps("got it \n", 0)
        size = len(data)
        conn.sendall(struct.pack(">L", size) + data) # Send data back to Atlas 200 DK 
    
    # Right
    elif data=="right\n":
        print("Right")
        if current_hg_command == "none":
            count_takeapicture = 0
            count_forward = 0
            count_backward = 0
            print("Right triggered \n\n")
            current_hg_command = "right"
            data = pickle.dumps("received right\n", 0)
        else: 
            data = pickle.dumps("got it \n", 0)
        size = len(data)
        conn.sendall(struct.pack(">L", size) + data) # Send data back to Atlas 200 DK

    # Activate
    elif data=="activate\n":
        print("activate robot\n")
        display = "default"
        count_takeapicture = 0
        count_forward = 0
        count_backward = 0
        count_spin = 0
        data = pickle.dumps("received activate\n", 0)
        size = len(data)
        conn.sendall(struct.pack(">L", size) + data) # Send data back to Atlas 200 DK 
    
    # Deactivate
    elif data=="deactivate\n":
        print("deactivate robot\n")
        display = "deactivate"
        count_takeapicture = 0
        count_forward = 0
        count_backward = 0
        count_spin = 0
        data = pickle.dumps("received deactivate\n", 0)
        size = len(data)
        conn.sendall(struct.pack(">L", size) + data) # Send data back to Atlas 200 DK 

    # RESET
    elif data=="reset\n":
        print("reset robot\n")
        if display != "deactivate":
            display = "default"
        count_takeapicture = 0
        count_forward = 0
        count_backward = 0
        count_spin = 0
        data = pickle.dumps("received reset\n", 0)
        size = len(data)
        conn.sendall(struct.pack(">L", size) + data) # Send data back to Atlas 200 DK 

    # Follow
    elif data=="follow\n":
        print("follow\n")
        display = "follow"
        count_takeapicture = 0
        count_forward = 0
        count_backward = 0
        count_spin = 0
        data = pickle.dumps("received follow\n", 0)
        size = len(data)
        conn.sendall(struct.pack(">L", size) + data) # Send data back to Atlas 200 DK

    # Stop follow
    elif data=="stop_follow\n":
        print("stop following\n")
        display = "default"
        count_takeapicture = 0
        count_forward = 0
        count_backward = 0
        count_spin = 0
        data = pickle.dumps("received stop_follow\n", 0)
        size = len(data)
        conn.sendall(struct.pack(">L", size) + data) # Send data back to Atlas 200 DK

    # Body detected
    elif data == "body\n":
        print("body\n")
        display = "body"
        data = pickle.dumps("received body\n", 0)
        size = len(data)
        conn.sendall(struct.pack(">L", size) + data) # Send data back to Atlas 200 DK

    # Centering for take a picture
    elif data=="center for picture\n":
        print("center for picture\n")
        display = "picture"
        data = pickle.dumps("received center\n", 0)
        size = len(data)
        conn.sendall(struct.pack(">L", size) + data) # Send data back to Atlas 200 DK

    # Nothing to send, report "none" to Atlas anyways
    elif data=="none\n":
            # display = "default"
            if display == "body":
                display = "default"
            count_takeapicture = 0
            count_forward = 0
            count_backward = 0
            count_spin = 0
            data = pickle.dumps("got it\n", 0)
            size = len(data)
            conn.sendall(struct.pack(">L", size) + data) # Send data back to Atlas 200 DK 

    # Else, received photo from Atlas for Camera View feature of Take a Photo routine
    else:
        # print(data)
        frame = data
        frame = cv2.imdecode(frame, cv2.IMREAD_COLOR)
        height_orig, width_orig, channels = frame.shape
        if time_tap_start == 0:
            time_tap_start = time.time()
        else:
            time_tap_start = time_tap_start
        if (width_orig>1 and height_orig>1): #Verify that image is valid
            frame_show = cv2.resize(frame, (width, height))
            
        # After 3 seconds of countdown, flash white on the screen and display the final taken picture for 5 seconds
        if current_hg_command == "take_a_picture" and (time.time() - time_tap_start) > 3: 
            data = pickle.dumps("done command\n", 0)
            current_hg_command = "tap_image_fade" # "Take a picture" image flashes white
            time_tap_image_fade = time.time()
            time_tap_start = 0
            fade_image = frame_show

        # Imprint countdown number on photo for Camera View (3...2...1...)
        else:
            cv2.putText(frame_show,str(int(math.ceil(3 - (time.time() - time_tap_start)))),(200,210),font, scale,color,thickness,cv2.LINE_AA)
            data = pickle.dumps("got it\n", 0)

        # Send data back to Atlas 200 DK 
        size = len(data)
        conn.sendall(struct.pack(">L", size) + data)

####################### vv State Machine for Current Hand Gesture Command vv ######################

    # Display Neutral expression by default
    if current_hg_command != "take_a_picture" and current_hg_command != "tap_image_fade" and current_hg_command != "tap_final_image_show":

        ret_val, frame_show = neu_cap.read()
        # Reset to beginning if neutral expression video has ended
        if not ret_val:
            neu_cap.set(cv2.CAP_PROP_POS_FRAMES, 0)
            ret_val, frame_show = neu_cap.read()
        frame_show = cv2.resize(frame_show, (width, height))

        # if current_hg_command == "forwards": #for debugging
        #     cv2.putText(frame_show,"F",(200,210),font, scale,color,thickness,cv2.LINE_AA)
        # if current_hg_command == "backwards": #for debugging
        #     cv2.putText(frame_show,"B",(200,210),font, scale,color,thickness,cv2.LINE_AA)
        # if current_hg_command == "spin": #for debugging
        #     cv2.putText(frame_show,"S",(200,210),font, scale,color,thickness,cv2.LINE_AA)

        if display == "deactivate":
            frame_show = cv2.resize(deactivate_img, (width, height))

        elif display == "picture":
            frame_show = cv2.resize(camera_img, (width, height))

        elif display == "follow":
            frame_show = cv2.resize(follow_img, (width, height))

        elif display == "body":
            frame_show = cv2.resize(body_img, (width, height))


#    ### Display happy mood after completion of any command. Return to neutral expression when complete
#     elif current_hg_command == "happy_mood":
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

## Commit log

2021-02-17 ML Initial
    Initial upload of ML 3 chained (face detection, hand detection, and hand gesture), models are uploaded separately because they are large files
2021-02-23 Add files via upload
    Display countdown feature on top of the camera view (USB camera connected to Rpi) .
    Need to transfer the view to LCD screen
2021-02-23 Added camera servo control
2021-02-24 Update servo control
2021-03-23 Rpi and Atlas code - (nearly) full software system
    Includes Raspberry Pi software for: serial communication, mood expression, execution of hand gesture commands, camera view, servo camera adjustment feature, RC car base control, and saving images (on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
    Includes Atlas 200DK software for: serial communication, hand gesture recognition and hg command computation, and computing necessary servo movements (face detection)
    DON'T FORGET!! Download the three models and move them into "model" folder under "Atlas_robot_pet" folder! Also change IP addresses as needed. :)
2021-03-30 RC car base initialization/Added count to command
    RC car base initialization was moved out of function to just before main while loop in Raspberry pi main code. A count was added in Raspberry Pi main code (as well as very minor changes to main.py fo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
2021-04-14 Added 3D models
    [bracket.STL, cameraMount.STL, panTilt.STL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]
2021-05-01 Add files via upload
    3D Printing Files
    [DK_Cup.SLDPRT, DK_Cup_screen.SLDPRT, DK_holder_arm.SLDPRT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]
2021-05-08 Repo diagram
    [DK_Cup_screen.STL, DK_holder_arm.STL, DK_holder_main.STL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]
2022-02-26 Add new presenter server scripts that allow wireless connections
2022-03-13 validate body in frame
2022-03-25 Add files via upload
    new 3D parts added
    [DK_holder.STL, power_bank_holder.STL, router holder.STL]
2022-03-26 Add current PI code
2022-03-27 Bug fixes related to take_a_picture and follow modes.
    [server_v9.py]
2022-04-01 Fix take_a_picture and spin.
    [server_v9.py]
2022-04-22 3D models
    [DK_holder_arm.STL, DK_holder_bottom.STL, DK_holder_main.STL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]
